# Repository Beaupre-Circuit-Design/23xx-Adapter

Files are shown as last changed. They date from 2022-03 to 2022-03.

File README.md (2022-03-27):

# 23xx Adapter

# Introduction

This is a rework of the excellent design made by Jim Brain to replace a 23xx ROM with a standard JEDEC 28 or 32 pin EPROM/EEPROM or Flash ROM. The main difference, this version is 1.9mm smaller in width and more centered on the socket, allowing enough spacing to replace all three roms in a C64 long-board version where Jim's is a little bit too large to install two side by side.

Since 23xx ROMs can be produced with active high or low select lines, the adapter can decode theses signals and select the ROM on the right one. Also the highest address lines not used by the original ROM are available via SMT pads for permanent configuration, or headers to allow bank dynamic bank switching.

# Configuration

The onboard 74HCT138 3-to-8 decoder converts any combination of the 3 possible chip select lines into a single JEDEC standard select line.  If a select line is not needed, that input can be tied to ground via SMT pads on the bottom of the PCB.

|Pad|Position| |
|---|---|---|
|18 |1-2 |Line is routed to adress line A11, SMT Pad A should be solder close |
|18 |2-3 |Line is used as chip select, A11 can be drive by the SMT Pad or header|
|20 |1-2 |Line is routed to <span style="text-decoration:overline">OE</span> |
|20 |2-3 |Line is used as chip select |
|21 |1-2 |Line is routed to adress line A12, SMT Pad C should be solder close |
|20 |2-3 |Line is used as chip select, A12 can be drive by the SMT Pad or header|

Once configured, the following truth table show all the possible output at SMT Pads 0-7, solder the pad that is low when the original chip is selected.

|18|20|21|0|1|2|3|4|5|6|7|
|--|--|--|-|-|-|-|-|-|-|-|
|L |L |L |L|H|H|H|H|H|H|H|
|H |L |L |H|L|H|H|H|H|H|H|
|L |H |L |H|H|L|H|H|H|H|H|
|H |H |L |H|H|H|L|H|H|H|H|
|L |L |H |H|H|H|H|L|H|H|H|
|H |L |H |H|H|H|H|H|L|H|H|
|L |H |H |H|H|H|H|H|H|L|H|
|H |H |H |H|H|H|H|H|H|H|L|

## Configuration example for common ICs

|IC Model|Notes |A|B|C|18 |20 |21 |0|1|2|3|4|5|6|7||
|---|---|:-:|:-:|:-:|:-:|:-:|:-:|:-:|:-:|:-:|:-:|:-:|:-:|:-:|:-:|:-:|
|2316 |!CS1, !CS2, CS3 | | | |2-3|2-3|2-3| | | | |X| | | |2316: !CS1, !CS2, CS3|
|2716 |!EP, !G, Vpp | | | |2-3|2-3|2-3| | | | |X| | | |2716: !EP, !G, Vpp|
|2332 |!CS1, CS2 |X| | |1-2|2-3|2-3| | | | |X| | | |2332: !CE1, CE2|
|2364 |!CS1 |X| |X|1-2|2-3|1-2|X| | | | | | | |2364: !CE1|
|2364 |!CS1</br>(Alt, no 74LS138 decoding)| | | |1-2|1-2|1-2| | | | | | | | |2364: !CE! Alt|
|2364 |CS1 |X| |X|1-2|2-3|1-2| | |X| | | | | |2364: CE1|

## Notes if using EEPROM
Do not forget to pull-up the <span style="text-decoration:overline">WE</span> pin or you risk overwriting your EEPROM. As example if using a 28C64/256, solder pad A14, or for 28C512/010/040, solder pad A18.

## Rom banking

Depending on the size of the original and replacement rom, address lines 11 to 18 are available for bank switching, eiter by solder pads or using the 1.27mm header as shown in the pictures below.

|Solder Pads|1.27mm Header|
|:---:|:---:|
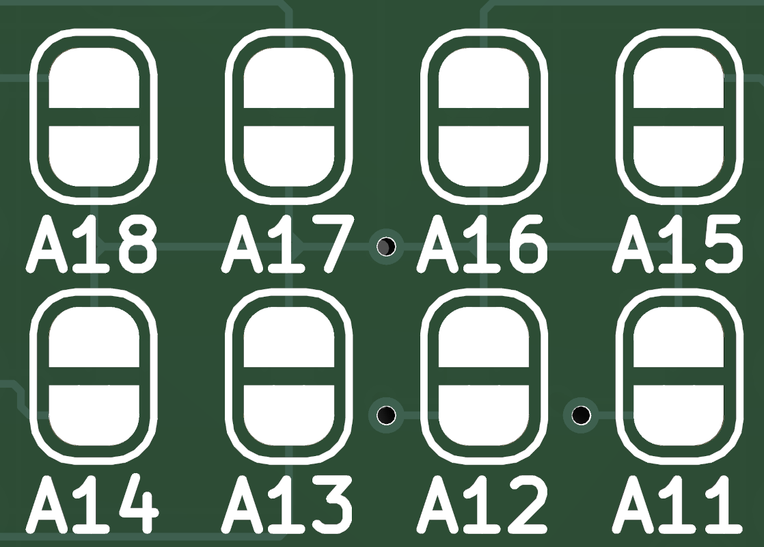
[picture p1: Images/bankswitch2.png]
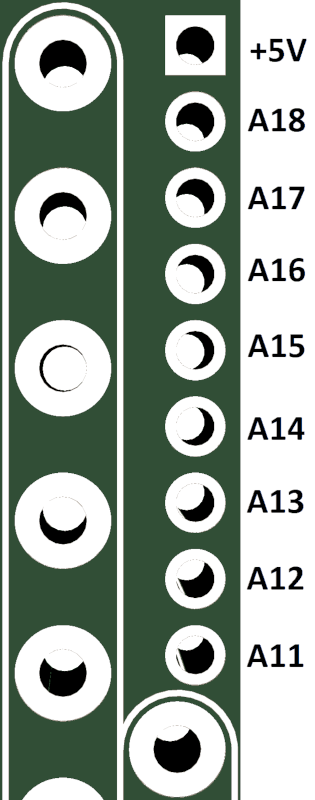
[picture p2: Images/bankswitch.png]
|||

# Components and assembly

[Gerbers files](Gerbers/) and SMD assembly files are available for uploading to your prefered manufacturer (I personnally use JLCPCB).  The PCB use SMT parts, except for the headers) while the control board use through-hole components. Refer to the [Bill of Materials](23xx_Adapter_Bom.xlsx) Excel sheet for a complete list of needed components.

# Licence

This work is licensed under the Creative Commons Attribution-NonCommercial-ShareAlike 4.0 International License. To view a copy of this license, visit http://creativecommons.org/licenses/by-nc-sa/4.0/ or send a letter to Creative Commons, PO Box 1866, Mountain View, CA 94042, USA.

# Revision History

|Revision  |Description |
|:---:|---|
|1.0 |Initial prototype |
|2.0 |Add bank switching header |

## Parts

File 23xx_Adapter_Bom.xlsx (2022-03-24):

Ref | Value | Footprint | Datasheet | Manufacturer | Mfr.Part | LCSC | Digikey | AliExpress | Notes
R1 | 10KΩ | Resistor_SMD:R_0603_1608Metric | https://datasheet.lcsc.com/lcsc/2110260030_UNI-ROYAL-Uniroyal-Elec-0603WAF1002T5E_C25804.pdf | Uniroyal Electronics | 0603WAF1002T5E | C25804
R2 | 10KΩ | Resistor_SMD:R_0603_1608Metric | https://datasheet.lcsc.com/lcsc/2110260030_UNI-ROYAL-Uniroyal-Elec-0603WAF1002T5E_C25804.pdf | Uniroyal Electronics | 0603WAF1002T5E | C25804
R3 | 10KΩ | Resistor_SMD:R_0603_1608Metric | https://datasheet.lcsc.com/lcsc/2110260030_UNI-ROYAL-Uniroyal-Elec-0603WAF1002T5E_C25804.pdf | Uniroyal Electronics | 0603WAF1002T5E | C25804
R4 | 10KΩ | Resistor_SMD:R_0603_1608Metric | https://datasheet.lcsc.com/lcsc/2110260030_UNI-ROYAL-Uniroyal-Elec-0603WAF1002T5E_C25804.pdf | Uniroyal Electronics | 0603WAF1002T5E | C25804
R5 | 10KΩ | Resistor_SMD:R_0603_1608Metric | https://datasheet.lcsc.com/lcsc/2110260030_UNI-ROYAL-Uniroyal-Elec-0603WAF1002T5E_C25804.pdf | Uniroyal Electronics | 0603WAF1002T5E | C25804
R6 | 10KΩ | Resistor_SMD:R_0603_1608Metric | https://datasheet.lcsc.com/lcsc/2110260030_UNI-ROYAL-Uniroyal-Elec-0603WAF1002T5E_C25804.pdf | Uniroyal Electronics | 0603WAF1002T5E | C25804
R7 | 10KΩ | Resistor_SMD:R_0603_1608Metric | https://datasheet.lcsc.com/lcsc/2110260030_UNI-ROYAL-Uniroyal-Elec-0603WAF1002T5E_C25804.pdf | Uniroyal Electronics | 0603WAF1002T5E | C25804
R8 | 10KΩ | Resistor_SMD:R_0603_1608Metric | https://datasheet.lcsc.com/lcsc/2110260030_UNI-ROYAL-Uniroyal-Elec-0603WAF1002T5E_C25804.pdf | Uniroyal Electronics | 0603WAF1002T5E | C25804
U2 | 74HCT138 | Package_SO:SOIC-16_3.9x9.9mm_P1.27mm | https://datasheet.lcsc.com/lcsc/1912111437_Texas-Instruments-SN74HCT138DR_C352958.pdf | Texas Instruments | SN74HCT138DR | C352958
 | 1x14 Straight Circular Pins P=2.54mm Male Pin Header |  | https://datasheet.lcsc.com/lcsc/2005111003_XFCN-MH254V-11-40-1000_C492237.pdf | XFCN | MH254V-11-40-1000 | C492237
 | 1x14 Straight Circular Pins P=2.54mm Male Pin Header |  | https://datasheet.lcsc.com/lcsc/2005111003_XFCN-MH254V-11-40-1000_C492237.pdf | XFCN | MH254V-11-40-1000 | C492237
 | 1x16 Straight Circular Holes P=2.54mm Female Header |  | https://datasheet.lcsc.com/lcsc/2004092110_XFCN-MF254V-11-40-0743_C510959.pdf | XFCN | MF254V-11-40-0743 | C510959
 | 1x16 Straight Circular Holes P=2.54mm Female Header |  | https://datasheet.lcsc.com/lcsc/2004092110_XFCN-MF254V-11-40-0743_C510959.pdf | XFCN | MF254V-11-40-0743 | C510959
 | 1x9 Straight Square Pins P=1.27mm Male Header |  | https://datasheet.lcsc.com/lcsc/2201121730_DEALON-DZ127R-11-09-25_C2935949.pdf | DEALON | DZ127R-11-09-25 | C2935949

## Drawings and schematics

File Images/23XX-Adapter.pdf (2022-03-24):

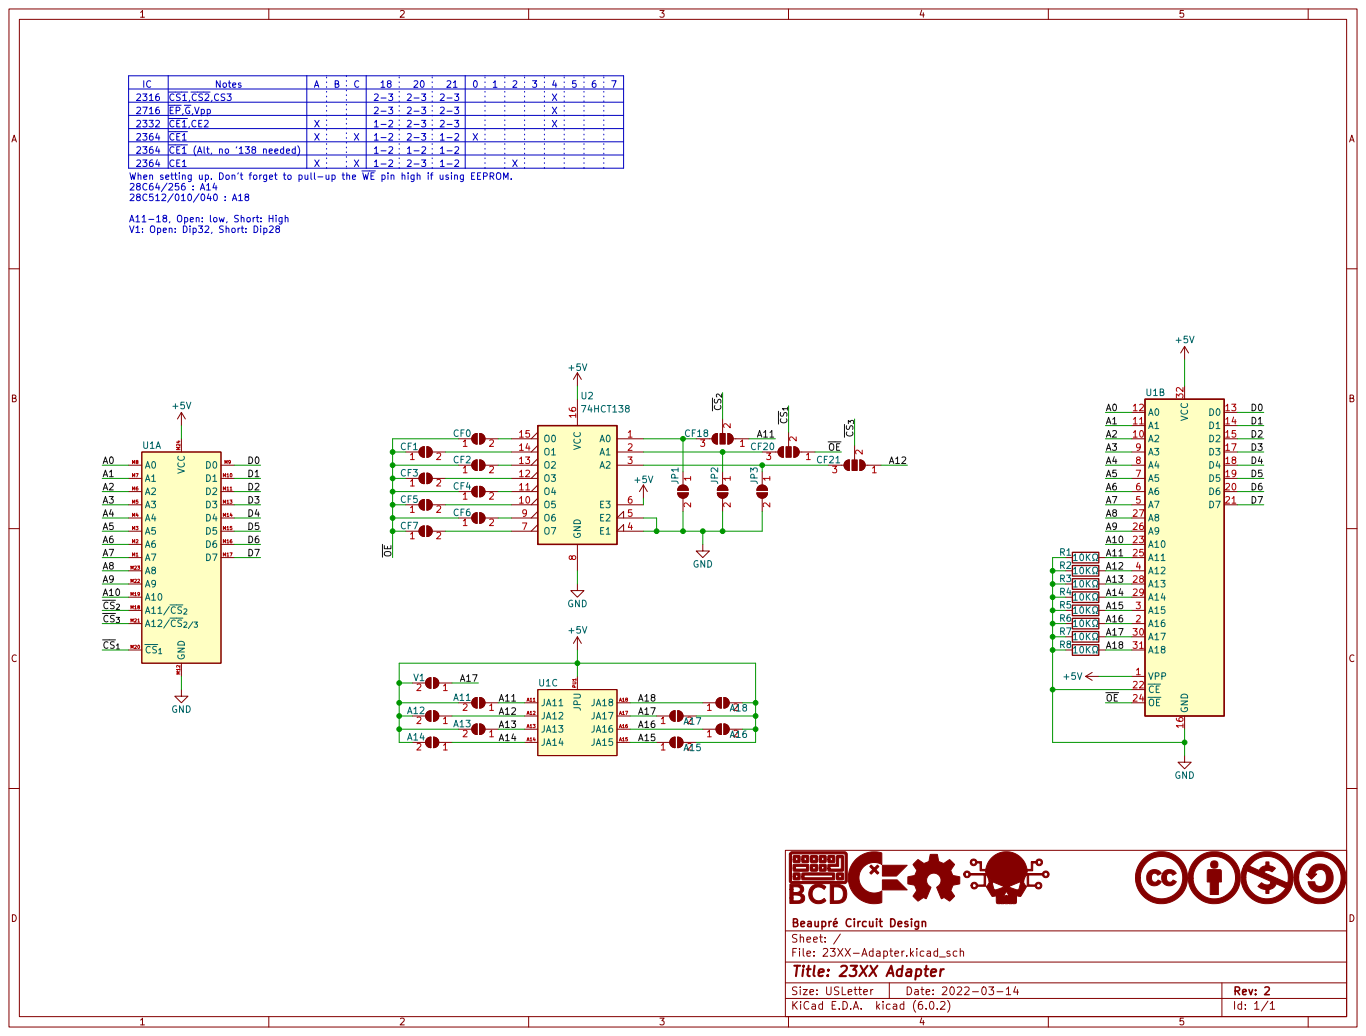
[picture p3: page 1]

2716 | ~{CE1} (Alt, no '138 needed) Notes ~{EP},~{G},Vpp | | B | | 2-3 | 2-3 | 2-3

2332 | ~{CE1},CE2 | X | | | 1-2 | 2-3 | | | | | | X
2364 | ~{CE1} | X | | X | 1-2 | 2-3 | 1-2 | X
2364 | | | | | 1-2 | 1-2 | 1-2
2364 | CE1 | | | | 1-2 | 2-3 | 1-2 | | | X

X When setting up. Don't forget to pull-up the ~{WE} pin high if using EEPROM. 28C64/256 : A14

28C512/010/040 : A18 A11-18, Open: low, Short: High

File: 23XX-Adapter.kicad_sch Sheet: / þÿBeaupré Circuit Design

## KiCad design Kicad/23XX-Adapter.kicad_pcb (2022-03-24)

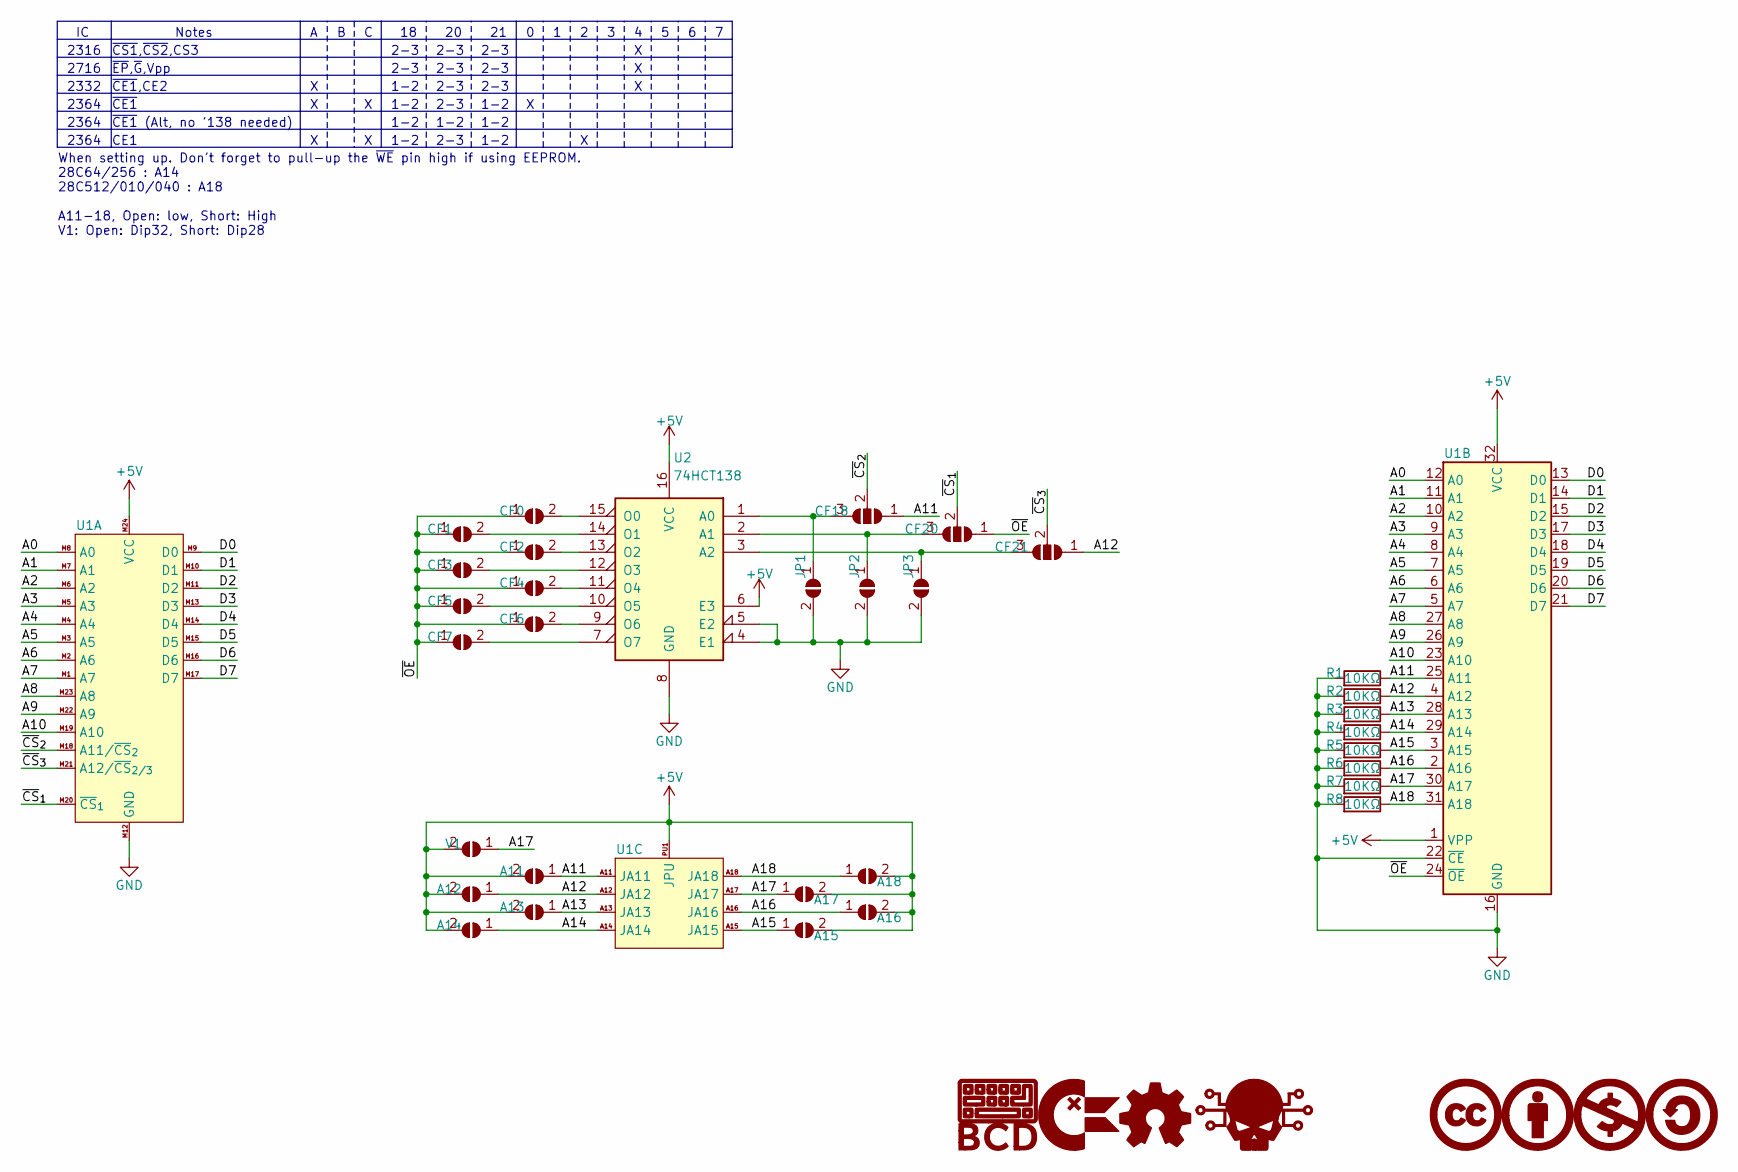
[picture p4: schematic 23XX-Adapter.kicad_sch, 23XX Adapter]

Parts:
A11, A12, A13, A14, A15, A16, A17, A18: SolderJumper_2_Open; SolderJumper-2_P1.3mm_Open_RoundedPad1.0x1.5mm
CF0, CF1, CF2, CF3, CF4, CF5, CF6, CF7: SolderJumper_2_Open; SolderJumper-2_P1.3mm_Open_RoundedPad1.0x1.5mm
CF18, CF20, CF21: SolderJumper_3_Open; SolderJumper-3_P1.3mm_Open_RoundedPad1.0x1.5mm_NumberLabels
G1: BCD_Logo; BCD_Logo_5mm
G2: ChickenLips; ChickenLips_2.5mm
G3: OpenSource_Hardware; Open_Source_Hardware_2.5mm
G4: CreativeCommons; CreativeCommons_2.5mm
G5: CreativeCommons_NonCommercial; CreativeCommons_NonCommercial_2.5mm
G6: CreativeCommons_Attribution; CreativeCommons_Attribution_2.5mm
G7: CreativeCommons_ShareAlike; CreativeCommons_ShareAlike_2.5mm
G8: Skull; Skull_2.5mm
JP1, JP2, JP3: SolderJumper_2_Open; SolderJumper-2_P1.3mm_Open_RoundedPad1.0x1.5mm
R1, R2, R3, R4, R5, R6, R7, R8: 10KΩ; R_0603_1608Metric; Mfr.Part 0603WAF1002T5E; LCSC C25804
U1: MOS_23xx_to_27xxx
U2: 74HCT138; SOIC-16_3.9x9.9mm_P1.27mm; Mfr.Part SN74HCT138DR; LCSC C352958
V1: SolderJumper_2_Open; SolderJumper-2_P1.3mm_Open_RoundedPad1.0x1.5mm

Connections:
+5V: A11.2 (B), A12.2 (B), A13.2 (B), A14.2 (B), A15.2 (B), A16.2 (B), A17.2 (B), A18.2 (B), U1.1 (VPP), U1.32 (VCC), U1.M24 (VCC), U1.PU1 (JPU), U2.6 (E3), U2.16 (VCC), V1.2 (B)
/A0: U1.12 (A0), U1.M8 (A0)
/A1: U1.11 (A1), U1.M7 (A1)
/A2: U1.10 (A2), U1.M6 (A2)
/A3: U1.9 (A3), U1.M5 (A3)
/A4: U1.8 (A4), U1.M4 (A4)
/A5: U1.7 (A5), U1.M3 (A5)
/A6: U1.6 (A6), U1.M2 (A6)
/A7: U1.5 (A7), U1.M1 (A7)
/A8: U1.27 (A8), U1.M23 (A8)
/A9: U1.26 (A9), U1.M22 (A9)
/A10: U1.23 (A10), U1.M19 (A10)
/A11: A11.1 (A), CF18.1 (A), R1.1, U1.25 (A11), U1.A11 (JA11)
/A12: A12.1 (A), CF21.1 (A), R2.1, U1.4 (A12), U1.A12 (JA12)
/A13: A13.1 (A), R3.1, U1.28 (A13), U1.A13 (JA13)
/A14: A14.1 (A), R4.1, U1.29 (A14), U1.A14 (JA14)
/A15: A15.1 (A), R5.1, U1.3 (A15), U1.A15 (JA15)
/A16: A16.1 (A), R6.1, U1.2 (A16), U1.A16 (JA16)
/A17: A17.1 (A), R7.1, U1.30 (A17), U1.A17 (JA17), V1.1 (A)
/A18: A18.1 (A), R8.1, U1.31 (A18), U1.A18 (JA18)
/D0: U1.13 (D0), U1.M9 (D0)
/D1: U1.14 (D1), U1.M10 (D1)
/D2: U1.15 (D2), U1.M11 (D2)
/D3: U1.17 (D3), U1.M13 (D3)
/D4: U1.18 (D4), U1.M14 (D4)
/D5: U1.19 (D5), U1.M15 (D5)
/D6: U1.20 (D6), U1.M16 (D6)
/D7: U1.21 (D7), U1.M17 (D7)
/~CS_{1}: CF20.2 (C), U1.M20 (~CS_{1})
/~CS_{2}: CF18.2 (C), U1.M18 (A11/~CS_{2})
/~CS_{3}: CF21.2 (C), U1.M21 (A12/~CS_{2/3})
/~OE: CF0.1 (A), CF1.1 (A), CF2.1 (A), CF3.1 (A), CF4.1 (A), CF5.1 (A), CF6.1 (A), CF7.1 (A), CF20.1 (A), U1.24 (~OE)
GND: JP1.2 (B), JP2.2 (B), JP3.2 (B), R1.2, R2.2, R3.2, R4.2, R5.2, R6.2, R7.2, R8.2, U1.16 (GND), U1.22 (~CE), U1.M12 (GND), U2.4 (E1), U2.5 (E2), U2.8 (GND)
unnamed: CF0.2 (B), U2.15 (O0)
unnamed: CF1.2 (B), U2.14 (O1)
unnamed: CF2.2 (B), U2.13 (O2)
unnamed: CF3.2 (B), U2.12 (O3)
unnamed: CF4.2 (B), U2.11 (O4)
unnamed: CF5.2 (B), U2.10 (O5)
unnamed: CF6.2 (B), U2.9 (O6)
unnamed: CF7.2 (B), U2.7 (O7)
unnamed: CF18.3 (B), JP1.1 (A), U2.1 (A0)
unnamed: CF20.3 (B), JP2.1 (A), U2.2 (A1)
unnamed: CF21.3 (B), JP3.1 (A), U2.3 (A2)

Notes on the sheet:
1-2
2316
~{CS1},~{CS2},CS3
2-3
~{CE1}
~{EP},~{G},Vpp
CE1
2332
~{CE1},CE2
2364
When setting up. Don't forget to pull-up the ~{WE} pin high if using EEPROM. 28C64/256 : A14 28C512/010/040 : A18 A11-18, Open: low, Short: High V1: Open: Dip32, Short: Dip28
~{CE1} (Alt, no '138 needed)
Notes
2716

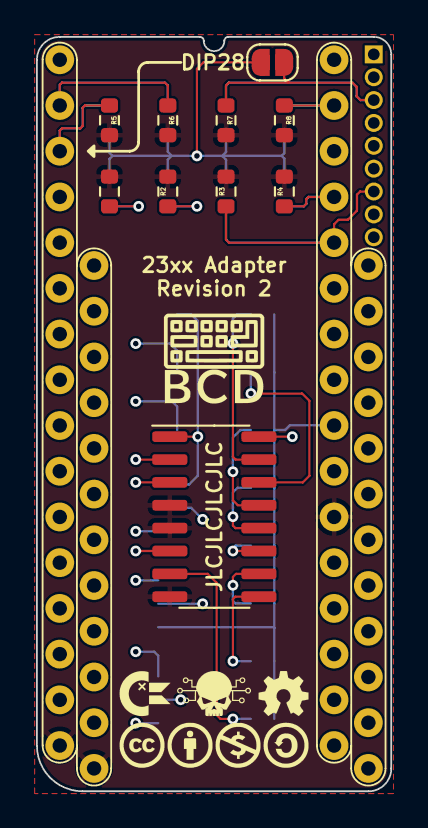
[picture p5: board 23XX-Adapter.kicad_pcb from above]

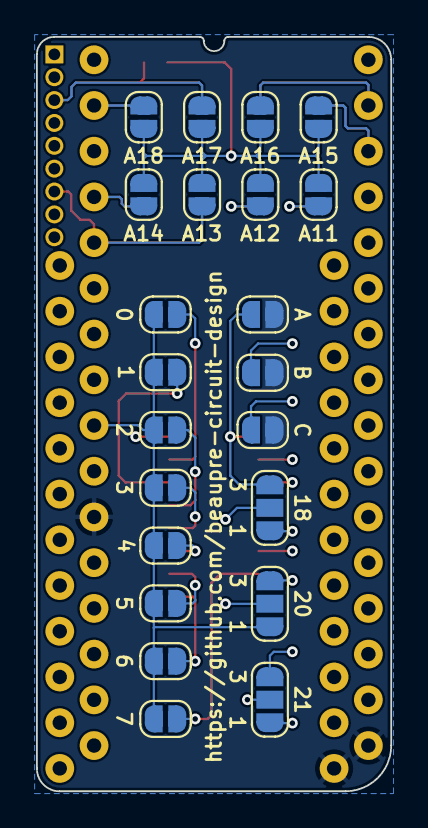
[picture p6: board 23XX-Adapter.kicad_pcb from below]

Board: 4 copper layers, 19.7 x 41.9 mm, 41 parts (22 on the bottom side), 44 nets.
